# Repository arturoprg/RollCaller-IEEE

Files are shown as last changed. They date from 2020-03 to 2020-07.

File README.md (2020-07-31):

# RollCaller-IEEE
RollCaller es un proyecto desarrollado por IEEE Student Branch of Granada con la finalidad de agilizar el proceso de pasar lista en las reuniones de la rama. Para ello se utiliza un sistema controlado por un Arduino nano que lee el código RFID asociado a la Tarjeta Universitaria (TUI) de los miembros.

La versión 2.0 utiliza solo el Arduino, mientras que la versión 3.0 utiliza Arduino y Python para guardar los registros de las tarjetas de forma independiente y mejorando la velocidad.

Uso versión 3.0: Tras conectar el arduino, inicia el programa de python y pasa las tarjetas, se creará un fichero con la fecha del día y la lista de los que han pasado la tarjeta.

Tras cargar RollCaller V3.0.ino en el dispositivo del Pasalista, ejecutamos el programa RollCaller V3.0.py y procedemos a pasar las tarjetas por el RollCaller, se creará un nuevo archivo de texto con la fecha del día donde se guardarán las personas que han pasado su tarjeta.

Si la tarjeta no está registrada, el programa de Python pedirá que introduzcas el nombre y apellidos del miembro, tras lo cuál quedará registrada la tarjeta y se añadirá a la lista de asistencia.

Crea un archivo llamado lista.txt donde se guardarán las tarjetas registradas de la siguiente forma:
Primer número
Segundo número
Tercer número
Cuarto número
Nombre y Apellidos

Para un correcto funcionamiento el archivo debe terminar con un salto de línea. Si el programa de Python tiene problemas leyendo lista.txt, puede que el archivo se haya corrompido, prueba a copiar el contenido del archivo en un nuevo archivo txt con el mismo nombre.

En RollCaller V3.0.py se puede editar el nombre del archivo que registra las tarjetas en la línea 5.

Página del proyecto: https://edu.ieee.org/es-ugr/proyectos/rollcaller/

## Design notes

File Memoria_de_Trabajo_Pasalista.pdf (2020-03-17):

## Memoria de Trabajo Pasalista

Líder de proyecto y único miembro: Arturo Pérez Rodríguez

Materiales: Arduino nano, Pantalla LCD y módulo Lector RFID, un par de leds, unas resistencias, cables, plástico PLC.

Presupuesto: 7,94€

Fecha de inicio: 2018 | Fecha de finalización: 17/10/2019

OBJETIVO

El objetivo de este proyecto es el de llevar a cabo un sistema cerrado que ayude a agilizar el proceso de pasar lista en las reuniones de la rama.

FUNDAMENTOS TEÓRICOS

Para pasar lista se aprovechará el código RFID de todas las tarjetas universitarias (TUIs) que poseen los miembros de la rama. Para aquellos miembros que no posean una TUI se les facilitará otra tarjeta con código RFID. El código de cada TUI será registrado y asignado a un texto que corresponderá a el nombre y apellidos del propietario de la TUI.

La lectura del código RFID se llevará a cabo con un módulo de Lector RFID conectado a un Arduino.

REALIZACIÓN

Lectura de los códigos.
Para este primer paso se utilizará el código llamado Codigos que se adjunta. El objetivo de este programa es escribir en el Serial de Arduino el código asignado a la tarjeta que se ha posicionado sobre el lector RFID. Estos códigos serán guardados junto con el nombre del usuario para crear una base de datos de los miembros.

Código del proyecto
Este código se llama Control_de_asistencia y su función es cuando una tarjeta se aproxima al lector RFID lee el código asignado a ésta que será un vector hexadecimal de 4 dígitos formados por un byte cada uno. Este código se comparará con los códigos registrados en la memoria del Arduino y si coincide con algún código de los registrados se encenderá un led verde y se imprimirá en la pantalla LCD el nombre asignado, complementariamente se escribirá el nombre en el Serial de Arduino desde donde es fácil copiar todos los nombres que se han escrito y pegarlos en un documento Word. Si no hay un código igual al de la tarjeta que se ha pasado se escribirá en la pantalla LCD “Tarjeta no valida” y se encenderá un led rojo, en este caso no se escribirá nada en el Serial.

Más tarde se ha realizado una nueva versión del código llamada Control_de_asistencia_2.0. Esta nueva versión busca solucionar algunos fallos de la versión anterior y pulir el código. La principal diferencia es que en este caso el texto escrito en la LCD y en el serial no es el mismo, puesto que para pasar lista es importante que los nombres estén con tildes, pero en la pantalla LCD aparecen símbolos extraños si intentas introducir caracteres con tildes. Para evitar esto el nombre del usuario pasará por una función que sustituye los caracteres con tilde por la vocal sin tilde correspondiente, ya sea en mayúscula o minúscula, además cortará el texto tras el segundo espacio para evitar escribir más texto del que es capaz de mostrar la LCD mostrándose de esta forma palabras cortadas en la mayoría de los casos. El texto impreso en el Serial no se cambia.

Además, se sustituye la forma de almacenar la información puesto que los códigos de la versión 1.0 se almacenaban cada uno en un vector distinto y en la versión 2.0 se almacenan todos en una matriz, y los nombres, antes escritos cada uno en una condición del tipo If… ahora se almacenan en un vector de caracteres. De esta forma se consigue que el código sea más claro, corto y fácil de añadir nuevos códigos y nombres, pero parece que el tiempo de respuesta es más lento para algunos casos.

Hardware
La disposición de los pines en el Arduino nano es la indicada en cada código. Todos los pines han sido soldados en una matriz de soldar junto con los leds y resistencias necesarias. El potenciómetro característico utilizado junto con las pantallas LCDs para regular su iluminación ha sido sustituido por un juego de resistencias que fijan una iluminación de la LCD adecuada.

Modelado 3D
Finalmente se ha diseñado una caja utilizando el SketchUp capaz de contener todo el hardware. Esta caja está formada por dos piezas unidas por tornillos y precisa de un hueco lateral para enchufar el Arduino al ordenador y 4 huecos frontales, 2 pequeños para los leds, y 2 más grandes para la pantalla LCD y el lector RFID.

CONCLUSIÓN

Ha resultado ser un proyecto interesante de realizar, sobre todo a nivel de programación. El resultado final cumple perfectamente con el objetivo planteado.

APÉNDICE

Donde se han comprado los materiales utilizados:

Pantalla LCD

https://es.aliexpress.com/item/32922004464.html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,searchweb201602_2,searchweb201603_52 (https://es.aliexpress.com/item/32922004464.html?s=p)

Arduino nano

https://www.amazon.es/Arduino-Placa-Elegoo-ATmega328P-Compatible/dp/B071HQBYFX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 Lector

RFID

https://es.aliexpress.com/item/32803648297.html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,searchweb201602_2,searchweb201603_52

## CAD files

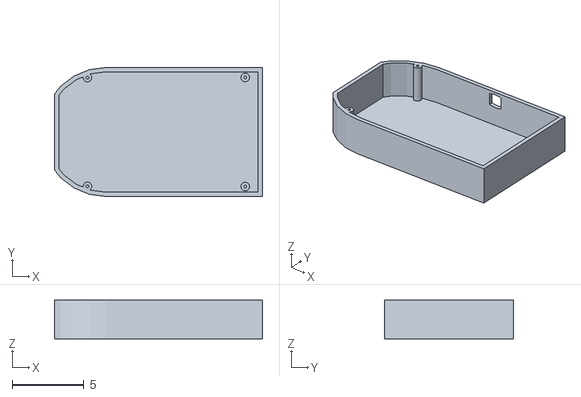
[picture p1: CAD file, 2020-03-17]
Base.stl
14.5 x 9.00 x 2.70

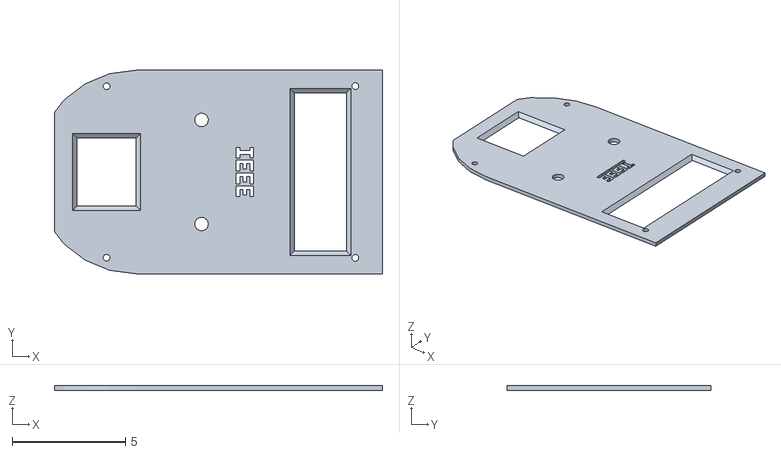
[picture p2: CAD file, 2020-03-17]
Tapa.stl
14.5 x 9.00 x 0.2

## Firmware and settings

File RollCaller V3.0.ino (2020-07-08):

//////////////////////////////////////////////////////////////////////////////////////////////////////////////
/// Programa para el control de la asistencia en las reuniones de IEEE ///////////////
//////////////////////////////////// by Arturo P. ///////////////////////////////////
/////////////////////////////////////////////////////////////////////////////////////
/*
 Conexiones:
  Módulo RC522, de izquierda a derecha:
   * 3.3V
   * Pin 9
   * Gnd
   * Libre
   * Pin 12
   * Pin 11
   * Pin 13
   * Pin 10

  Leds
  * Rojo  Pin A0
  * Verde Pin A1
  
  LCD 
  * Vss   Gnd
  * Vdd   5V
  * Vo    Potenciometro pin solo
  * RS    Pin 2
  * RW    Gnd
  * E     Pin 3
  * D0-D3 Libre
  * D4-D7 Pin 4-7
  * A     5V
  * K     Gnd
  * Conectar potenciometro a 5V y Gnd
 */

#include <SPI.h>            //Libreria Lector
#include <MFRC522.h>       //Libreria Lector
#include <LiquidCrystal.h> //Libreria LCD

#define RST_PIN  9    //Pin 9 para el reset del RC522
#define SS_PIN  10   //Pin 10 para el SS (SDA) del RC522
MFRC522 mfrc522(SS_PIN, RST_PIN); //Creamos el objeto para el RC522

LiquidCrystal lcd(2, 3, 4, 5, 6, 7);//Pines de la LCD

#define red A0
#define green A1
char lee;
int cont = 0;
byte ActualUID[4];

//Funcion para escribir en la LCD
void escribirLCD(char *linea0,char *linea1){
  lcd.setCursor(0, 0);
  lcd.print(linea0);
  lcd.setCursor(0, 1);
  lcd.print(linea1);
}

boolean compareArray(byte array1[],byte array2[])
{
  if(array1[0] != array2[0])return(false);
  if(array1[1] != array2[1])return(false);
  if(array1[2] != array2[2])return(false);
  if(array1[3] != array2[3])return(false);
  return(true);
}

//Esta función enciende el led rojo y dice Targeta no valida 
void ledRojo(){
  escribirLCD("Tarjeta no      ","registrada      ");
  digitalWrite(red,HIGH);
  delay(500);
  digitalWrite(red,LOW);
  delay(100);
  digitalWrite(red,HIGH);
  delay(400);
  digitalWrite(red,LOW);
}

void setup() { //definimos las entradas e iniciamos Serial, LCD y Lector 
  
  lcd.begin(16, 2); //Iniciamos LCD
  Serial.begin(9600); //Iniciamos La comunicacion serial
  SPI.begin();        //Iniciamos el Bus SPI
  mfrc522.PCD_Init(); // Iniciamos el MFRC522
  
  pinMode(red,OUTPUT);
  pinMode(green,OUTPUT);
  digitalWrite(red,LOW);
  digitalWrite(green,LOW);

  escribirLCD("Pase su tarjeta"," ");
}

void loop() {
  if (Serial.available() > 0){    // Mientras recibe de Python
    lee = Serial.read();          // Introduce lo que lee
    if (lee == '1'){              // Si recibe un 1 significa que no esta registrado el codigo
      ledRojo();
    }
    else if (lee == '2'){        // Si recibe un 2 significa que ha surgido algún error mientras funcionaba
      escribirLCD("Ha surgido un   ","error. Espere...");
      while (true){             // Entra en un bucle infinito (se reinicia al reiniciar Python
        digitalWrite(red,HIGH);
        delay(2000);
        digitalWrite(red,LOW);
        delay(2000);
      }
    }
    else if (cont == 0){      // Si es la primera letra, limpia la LCD
      escribirLCD("Buenas          ","                ");
      digitalWrite(green,HIGH);
      lcd.setCursor(cont, 1);
      lcd.print(lee);
      cont = cont+1;
    }
    else{                 // Escribe el resto de letras
      lcd.setCursor(cont, 1);
      lcd.print(lee);
      cont = cont+1;
    }
  }
  else{                 // Si deja de recibir, vuelve a la posicion de leer una tarjeta
    cont = 0;
    if (lee != '1'){
      digitalWrite(green,LOW);
      delay(1000);
      escribirLCD("Pase su tarjeta","             ");
    }
  }
  // Enviamos la tarjeta leida
  if ( mfrc522.PICC_IsNewCardPresent()) 
        {  
      //Seleccionamos una tarjeta
            if ( mfrc522.PICC_ReadCardSerial()&&!compareArray(ActualUID,mfrc522.uid.uidByte))
            {
                  // Enviamos serialemente su UID
                  for (byte i = 0; i < 4; i++) {
                          ActualUID[i]=mfrc522.uid.uidByte[i];
                          Serial.println(int(ActualUID[i]));
                  }
                  // Terminamos la lectura de la tarjeta tarjeta  actual
                  mfrc522.PICC_HaltA();    
                  }
            }

      }

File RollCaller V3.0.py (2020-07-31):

import serial       # Para la comunicacion Serial
from datetime import date   # Para obtener la fecha
import unidecode

listaTxt = 'AsIstEEEncia.txt'
puertoCorrecto = False
while(puertoCorrecto == False):
    try:            # Se conecta al puerto Serial
        puerto = input("Escribe el puerto al que se ha conectado el arduino (ej COM7):\n").upper()
        ser = serial.Serial(puerto)
        ser.reset_input_buffer()
        if puerto[-1] == " ":
            LaTex = "\item "
        else:
            LaTex = ""
        puertoCorrecto = True
    except:
        print("Puerto no válido\n")

def Lector():        # Lee la entrada Serial
    lec = []        # Array para guardar el codigo


    while len(lec)<4:   # Guarda el codigo en el Array
        try:
            ser_bytes = ser.readline()
            decoded_bytes = int(ser_bytes[0:len(ser_bytes)-2].decode("utf-8"))
            lec.append(str(decoded_bytes))
        except:
            ser.write(b'2')
            input("Keyboard Interrupt")
            break
    lec_tup = tuple(lec)    # Lo convierte en una tupla
    return(lec_tup)


def Procesar_txt(): # Procesa el archivo de texto con los codigos (lista.txt)
    try:
        listado = {}    # Diccionario para los codigos y nombres
        vector2 = []    # Array para
        codigos   = []  # Guarda los codigos
        nombres = []    # Guarda los nombres
        cont = 0        # Sirve de indice para navegar por el texto
        with open(listaTxt,encoding='utf-8') as archivo:
	           texto = archivo.readlines()
        # Creamos un vector con los nombres y otro con los codigos
        for i in texto:
            cont = cont + 1
            vector = i[0:-1]    # Guarda en vector una de las lineas de texto (menos el \n)
            if not cont%5 == 0:
                vector2.append(vector)  # Crea el codigo de 4 numeros
            else:
                nombres.append(vector)  # Añade un nombre
                codigos.append(vector2) # Añade un codigo
                cont = 0            # Reinicia el contador
                vector2 = []        # Reinicia el vector

        for i in range(len(nombres)):   # Se crea el dicionario
            listado[tuple(codigos[i])] = nombres[i]

    except:
        ser.write(b'2')
        input("Error con el archivo de la lista de códigos")
    return(listado)

def Anadir_txt(nombre,tupla):   # Añade un nombre a lista.txt
    try:
        with open(listaTxt,encoding='utf-8',mode="a") as archivo:  # Abre lista.txt
            for numero in tupla:                # Añade los numeros del codigo
                archivo.write(f"{int(numero)}\n")
            archivo.write(f"{nombre}\n")        # Añade el nombre
        with open(f"{date.today()}.txt","a") as archivo:    # Añade el nombre a la lista de hoy
            archivo.write(f"{LaTex}{nombre}\n")

    except:
        ser.write(b'2')
        input("Problemas añadiendo el nombre")
    return()

def Enviar(nombre):     # Pone el nombre que envia correcto para la LCD
    i = 2;
    sinTildes = unidecode.unidecode(nombre) # Quita las tildes
    try:
        while not sinTildes[i-2] == ' ':        # Deja el nombre y la primera letra del apellido
            i = i+1
            n = sinTildes[:i] + '.'
        ser.write(n.encode())                   # Envia el nombre
    except:
        ser.write(nombre.encode())                   # Envia el nombre tal cual (por si no tiene apellidos)
    return()

def main():
    Nombres = set({})           # Lista de los nombres que ya han pasado
    lista = Procesar_txt()      # Diccionario

    print(f"Asistencia {date.today()}\n")
    while True:                 # Bucle de funcionamiento
        lec_tup = Lector()      # Se lee la tarjeta
        if lec_tup in lista:    # Si el codigo esta en la lista, escribe el nombre em um txt
            nombre = lista.get(lec_tup)
            if not nombre in Nombres:
                Nombres.add(nombre)
                Enviar(nombre)
                with open(f"{date.today()}.txt","a") as archivo:
                    archivo.write(f"{LaTex}{nombre}\n")
                print(nombre)
        else:                   # Si no, te pide guardarlo
            ser.write(b'1')
            nombre_nuevo = input(f"No se encuentra el código {lec_tup}, introduce Nombre y Apellidos\n")
            Anadir_txt(nombre_nuevo,lec_tup)
            Nombres.add(nombre_nuevo)
            Enviar(nombre_nuevo)
            lista = Procesar_txt()
    return()

try:
    main()
finally:
    ser.close()     # Cierra la conexión serie con el Pasalista
